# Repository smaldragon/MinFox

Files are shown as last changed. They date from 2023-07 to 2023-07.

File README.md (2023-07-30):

# MinFox

**NOTE: As of now, the board is untested, this README will be updated once proper tests with the physical board have taken place**

This is a minimal 65c02 board for prototyping, it provides ROM, RAM, 6 Chip Select lines (S1-S6), and a large jumper header with all the required signals to connect to daughter boards or to breadboards. The goal is to have a dumb, as simple as possible board for testing peripherals connected to a 65c02 bus.

All components are through hole, as to allow for an easier soldering experience and for the installation of sockets for IC reuse.

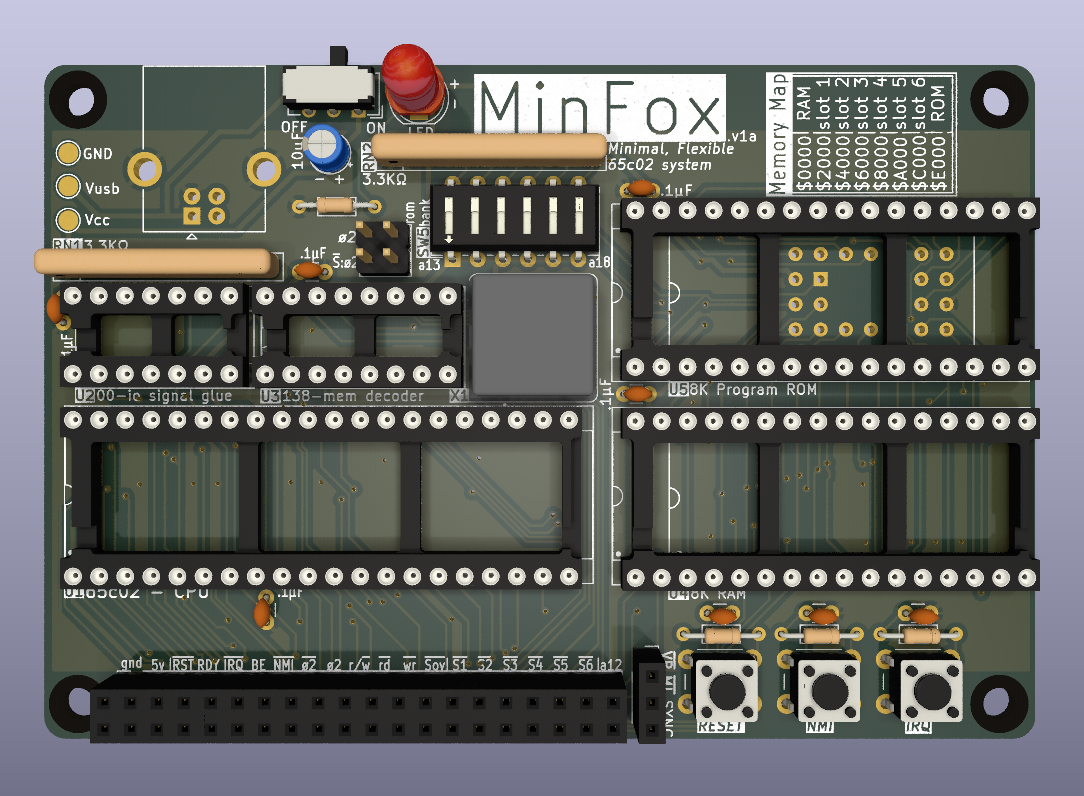
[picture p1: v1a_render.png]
Render of the board (v1a revision)


## Bill of Materials

* wdc65c02 CPU (dip-40)
* 74hc00 Quad Nand Gate (dip-14)
* 74hc138 3-to-8 Decoder (dip-16)
* Standard 62xxx SRAM (dip-28 or dip-32)
* Standard 28cXX EEPROM (dip-28) or 39SF0x0 Flash NOR (dip-32 or PLCC-32)
* Standard 1Mhz Clock Oscillator

* 2x20 Pin Socket (same size as RPi connector)
* 1x3  Pin Socket
* 2x2  Pin Header (+ 2 Jumpers)
* DIP-12 Switch
* Small 6-Pin Power Slide Switch
* USB-B Connector (power)

* 3xPush Buttons
* 1x470Ω
* 3x1KΩ
* 1x10µF Polarized Capacitor
* 8x0.1µF Capacitor
* 2x9pin Resistor Networks

The location and values of all components are also described in the board silk screen.

## Change Log

Board revisions  follow a `v$number$letter` naming scheme, the number symbolizes a board with new features and incompatibilities, while the letter symbolizes fixes and minor tweaks. The current version is **v1a**

### v1a

* Fixed breaking bug with /WR signal
* Added Screw Mounts
* Added Support for DIP-32 RAM and DIP-32/PLCC-32 Flash NOR chips
* Added Jumper for disconnecting clock oscillator
* Added Jumper for gating slot select signals with ø2
* Added dip switch for setting a ROM bank to use
* Added Set Overflow signal to the Connector
* Changed footprint of power slide switch
* Many tweaks to silkscreen

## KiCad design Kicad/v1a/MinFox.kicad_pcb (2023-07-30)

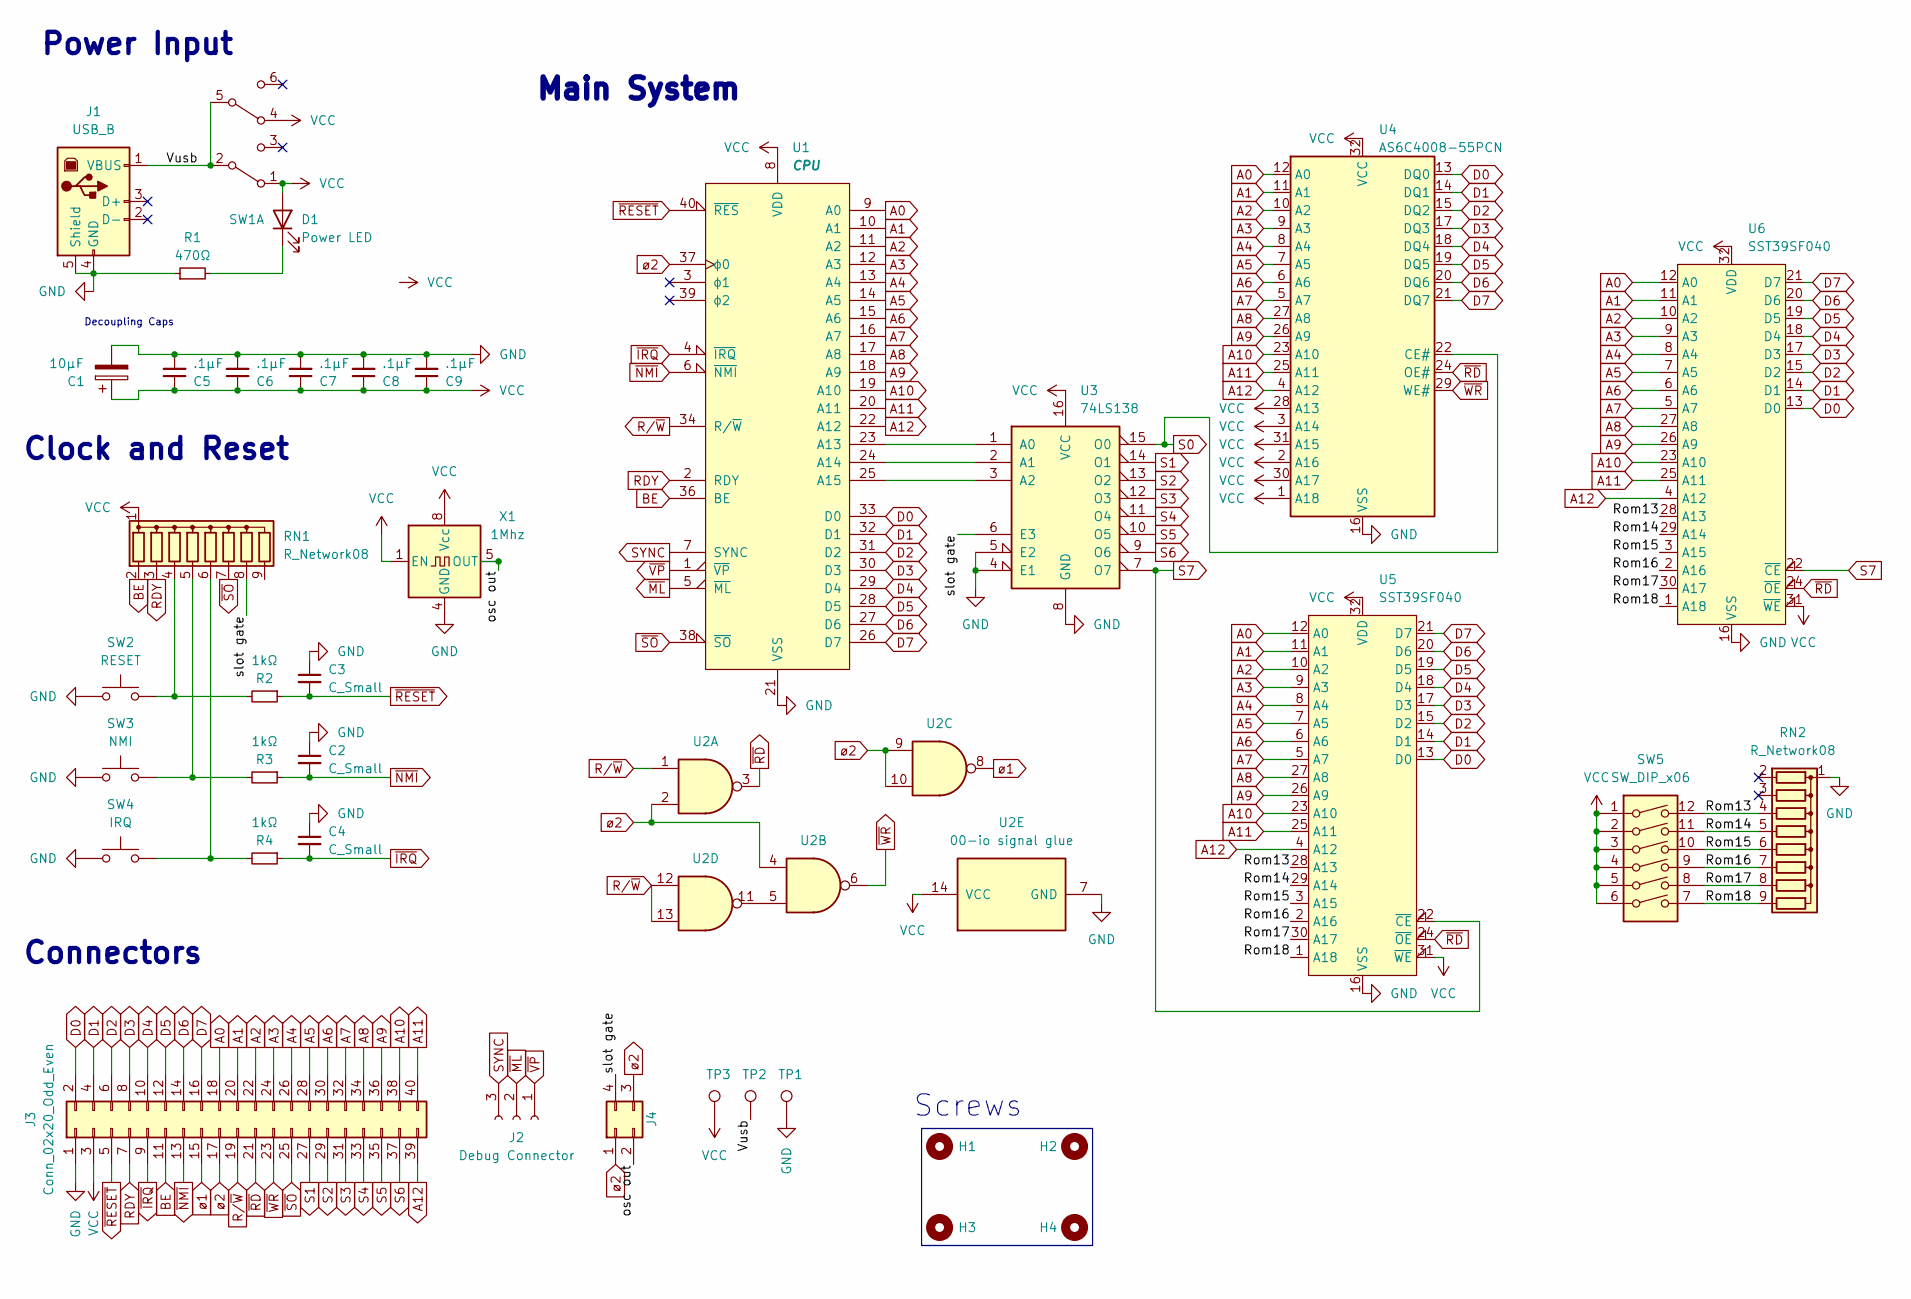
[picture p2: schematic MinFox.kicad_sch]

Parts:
C1: 10µF; CP_Radial_D4.0mm_P1.50mm
C2, C3, C4: C_Small; C_Disc_D3.0mm_W1.6mm_P2.50mm
C5, C6, C7, C8, C9: .1µF; C_Disc_D3.0mm_W1.6mm_P2.50mm
D1: Power LED; LED_D5.0mm
H1, H2, H3, H4: MountingHole; MountingHole_3.2mm_M3
J1: USB_B; USB_B_OST_USB-B1HSxx_Horizontal
J2: Debug Connector; PinSocket_1x03_P2.54mm_Vertical
J3: Conn_02x20_Odd_Even; PinSocket_2x20_P2.54mm_Vertical
J4: Conn_02x02_Counter_Clockwise; PinHeader_2x02_P2.54mm_Vertical
R1: 470Ω; R_Axial_DIN0204_L3.6mm_D1.6mm_P7.62mm_Horizontal
R2, R3, R4: 1kΩ; R_Axial_DIN0204_L3.6mm_D1.6mm_P7.62mm_Horizontal
RN1, RN2: R_Network08; R_Array_SIP9
SW1: SW_DPDT_x2; SW_CuK_JS202011AQN_DPDT_Angled
SW2: RESET; SW_PUSH_6mm
SW3: NMI; SW_PUSH_6mm
SW4: IRQ; SW_PUSH_6mm
SW5: SW_DIP_x06; SW_DIP_SPSTx06_Slide_6.7x16.8mm_W7.62mm_P2.54mm_LowProfile
TP1: GND; TestPoint_Pad_D2.0mm
TP2: Vusb; TestPoint_Pad_D2.0mm
TP3: Vcc; TestPoint_Pad_D2.0mm
U1: CPU; DIP-40_W15.24mm_Socket
U2: 00-io signal glue; DIP-14_W7.62mm_Socket
U3: 74LS138; DIP-16_W7.62mm_Socket
U4: AS6C4008-55PCN; DIP-32_W15.24mm_Socket
U5: SST39SF040; DIP-32_W15.24mm_Socket
U6: SST39SF040; PLCC-32_THT-Socket
X1: 1Mhz; Oscillator_DIP-8

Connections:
/Rom13: RN2.4 (R3), SW5.12, U5.28 (A13), U6.28 (A13)
/Rom14: RN2.5 (R4), SW5.11, U5.29 (A14), U6.29 (A14)
/Rom15: RN2.6 (R5), SW5.10, U5.3 (A15), U6.3 (A15)
/Rom16: RN2.7 (R6), SW5.9, U5.2 (A16), U6.2 (A16)
/Rom17: RN2.8 (R7), SW5.8, U5.30 (A17), U6.30 (A17)
/Rom18: RN2.9 (R8), SW5.7, U5.1 (A18), U6.1 (A18)
/Vusb: J1.1 (VBUS), SW1.2 (B), SW1.5 (B), TP2.1
/osc out: J4.2, X1.5 (OUT)
/slot gate: J4.4, RN1.8 (R7), U3.6 (E3)
A0: J3.18, U1.9 (A0), U4.12 (A0), U5.12 (A0), U6.12 (A0)
A1: J3.20, U1.10 (A1), U4.11 (A1), U5.11 (A1), U6.11 (A1)
A2: J3.22, U1.11 (A2), U4.10 (A2), U5.10 (A2), U6.10 (A2)
A3: J3.24, U1.12 (A3), U4.9 (A3), U5.9 (A3), U6.9 (A3)
A4: J3.26, U1.13 (A4), U4.8 (A4), U5.8 (A4), U6.8 (A4)
A5: J3.28, U1.14 (A5), U4.7 (A5), U5.7 (A5), U6.7 (A5)
A6: J3.30, U1.15 (A6), U4.6 (A6), U5.6 (A6), U6.6 (A6)
A7: J3.32, U1.16 (A7), U4.5 (A7), U5.5 (A7), U6.5 (A7)
A8: J3.34, U1.17 (A8), U4.27 (A8), U5.27 (A8), U6.27 (A8)
A9: J3.36, U1.18 (A9), U4.26 (A9), U5.26 (A9), U6.26 (A9)
A10: J3.38, U1.19 (A10), U4.23 (A10), U5.23 (A10), U6.23 (A10)
A11: J3.40, U1.20 (A11), U4.25 (A11), U5.25 (A11), U6.25 (A11)
A12: J3.39, U1.22 (A12), U4.4 (A12), U5.4 (A12), U6.4 (A12)
BE: J3.11, RN1.2 (R1), U1.36 (BE)
D0: J3.2, U1.33 (D0), U4.13 (DQ0), U5.13 (D0), U6.13 (D0)
D1: J3.4, U1.32 (D1), U4.14 (DQ1), U5.14 (D1), U6.14 (D1)
D2: J3.6, U1.31 (D2), U4.15 (DQ2), U5.15 (D2), U6.15 (D2)
D3: J3.8, U1.30 (D3), U4.17 (DQ3), U5.17 (D3), U6.17 (D3)
D4: J3.10, U1.29 (D4), U4.18 (DQ4), U5.18 (D4), U6.18 (D4)
D5: J3.12, U1.28 (D5), U4.19 (DQ5), U5.19 (D5), U6.19 (D5)
D6: J3.14, U1.27 (D6), U4.20 (DQ6), U5.20 (D6), U6.20 (D6)
D7: J3.16, U1.26 (D7), U4.21 (DQ7), U5.21 (D7), U6.21 (D7)
GND: C1.2, C2.1, C3.1, C4.1, C5.2, C6.2, C7.2, C8.2, C9.2, J1.4 (GND), J1.5 (Shield), J3.1, R1.1, RN2.1 (common), SW2.1, SW3.1, SW4.1, TP1.1, U1.21 (VSS), U2.7 (GND), U3.4 (E1), U3.5 (E2), U3.8 (GND), U4.16 (VSS), U5.16 (VSS), U6.16 (VSS), X1.4 (GND)
unnamed: D1.1 (K), R1.2
unnamed: R2.2, RN1.4 (R3), SW2.2
unnamed: R3.2, RN1.5 (R4), SW3.2
unnamed: R4.2, RN1.6 (R5), SW4.2
unnamed: U1.23 (A13), U3.1 (A0)
unnamed: U1.24 (A14), U3.2 (A1)
unnamed: U1.25 (A15), U3.3 (A2)
unnamed: U2.5, U2.11
RDY: J3.7, RN1.3 (R2), U1.2 (RDY)
R/~W: J3.19, U1.34 (R/~W), U2.1, U2.12, U2.13
S0: U3.15 (O0), U4.22 (CE#)
S1: J3.27, U3.14 (O1)
S2: J3.29, U3.13 (O2)
S3: J3.31, U3.12 (O3)
S4: J3.33, U3.11 (O4)
S5: J3.35, U3.10 (O5)
S6: J3.37, U3.9 (O6)
S7: U3.7 (O7), U5.22 (~CE), U6.22 (~CE)
SYNC: J2.3, U1.7 (SYNC)
VCC: C1.1, C5.1, C6.1, C7.1, C8.1, C9.1, D1.2 (A), J3.3, RN1.1 (common), SW1.1 (A), SW1.4 (A), SW5.1, SW5.2, SW5.3, SW5.4, SW5.5, SW5.6, TP3.1, U1.8 (VDD), U2.14 (VCC), U3.16 (VCC), U4.1 (A18), U4.2 (A16), U4.3 (A14), U4.28 (A13), U4.30 (A17), U4.31 (A15), U4.32 (VCC), U5.31 (~WE), U5.32 (VDD), U6.31 (~WE), U6.32 (VDD), X1.1 (EN), X1.8 (Vcc)
~IRQ: C4.2, J3.9, R4.1, U1.4 (~IRQ)
~ML: J2.2, U1.5 (~ML)
~NMI: C2.2, J3.13, R3.1, U1.6 (~NMI)
~RD: J3.21, U2.3, U4.24 (OE#), U5.24 (~OE), U6.24 (~OE)
~RESET: C3.2, J3.5, R2.1, U1.40 (~RES)
~SO: J3.25, RN1.7 (R6), U1.38 (~SO)
~VP: J2.1, U1.1 (~VP)
~WR: J3.23, U2.6, U4.29 (WE#)
ø1: J3.15, U2.8
ø2: J3.17, J4.1, J4.3, U1.37 (ϕ0), U2.2, U2.4, U2.9, U2.10

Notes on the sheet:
Clock and Reset
Main System
Screws
Decoupling Caps
Power Input
Connectors

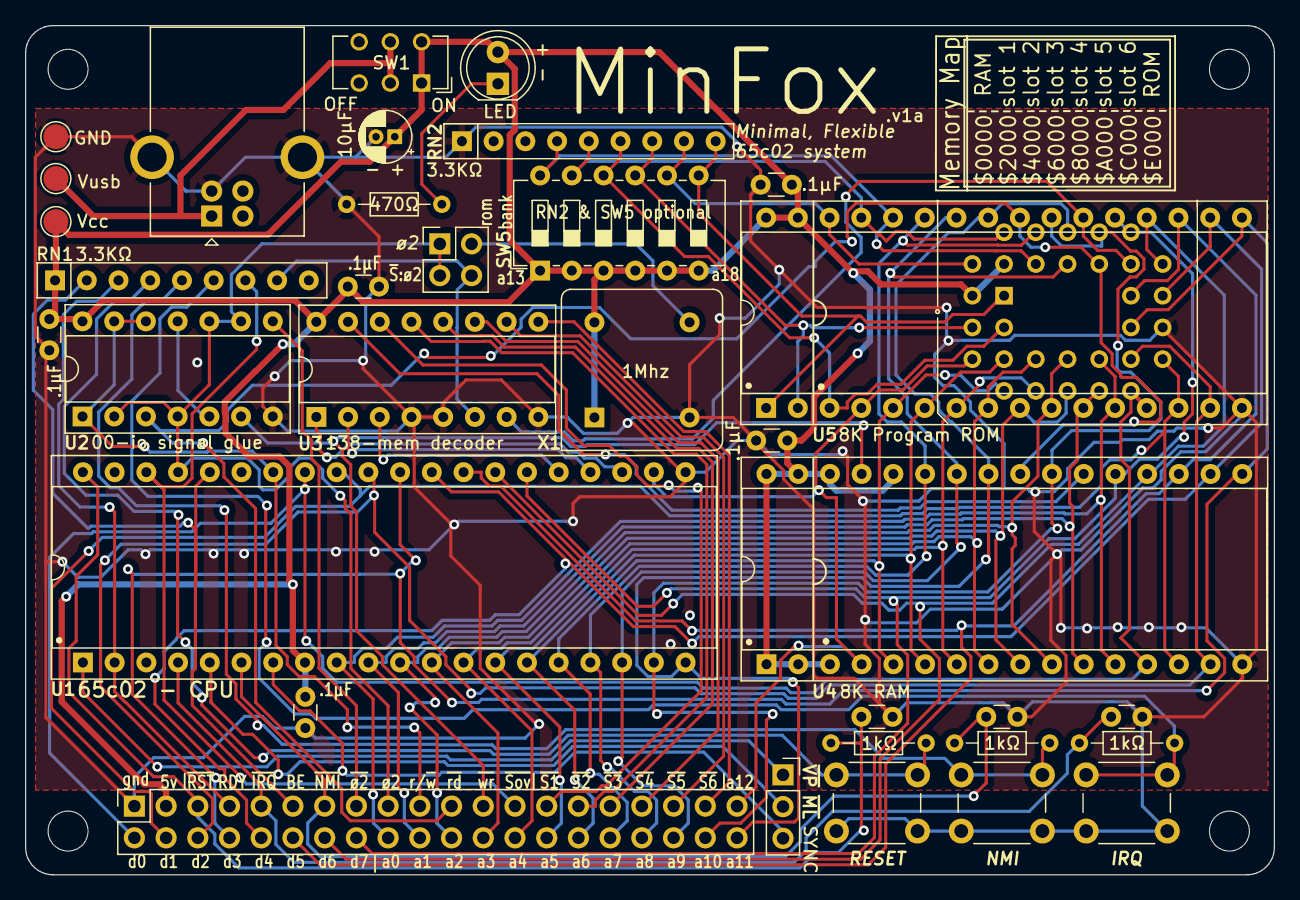
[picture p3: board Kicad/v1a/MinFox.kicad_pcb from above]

Board: 2 copper layers, 100.0 x 68.0 mm, 39 parts (0 on the bottom side), 62 nets.

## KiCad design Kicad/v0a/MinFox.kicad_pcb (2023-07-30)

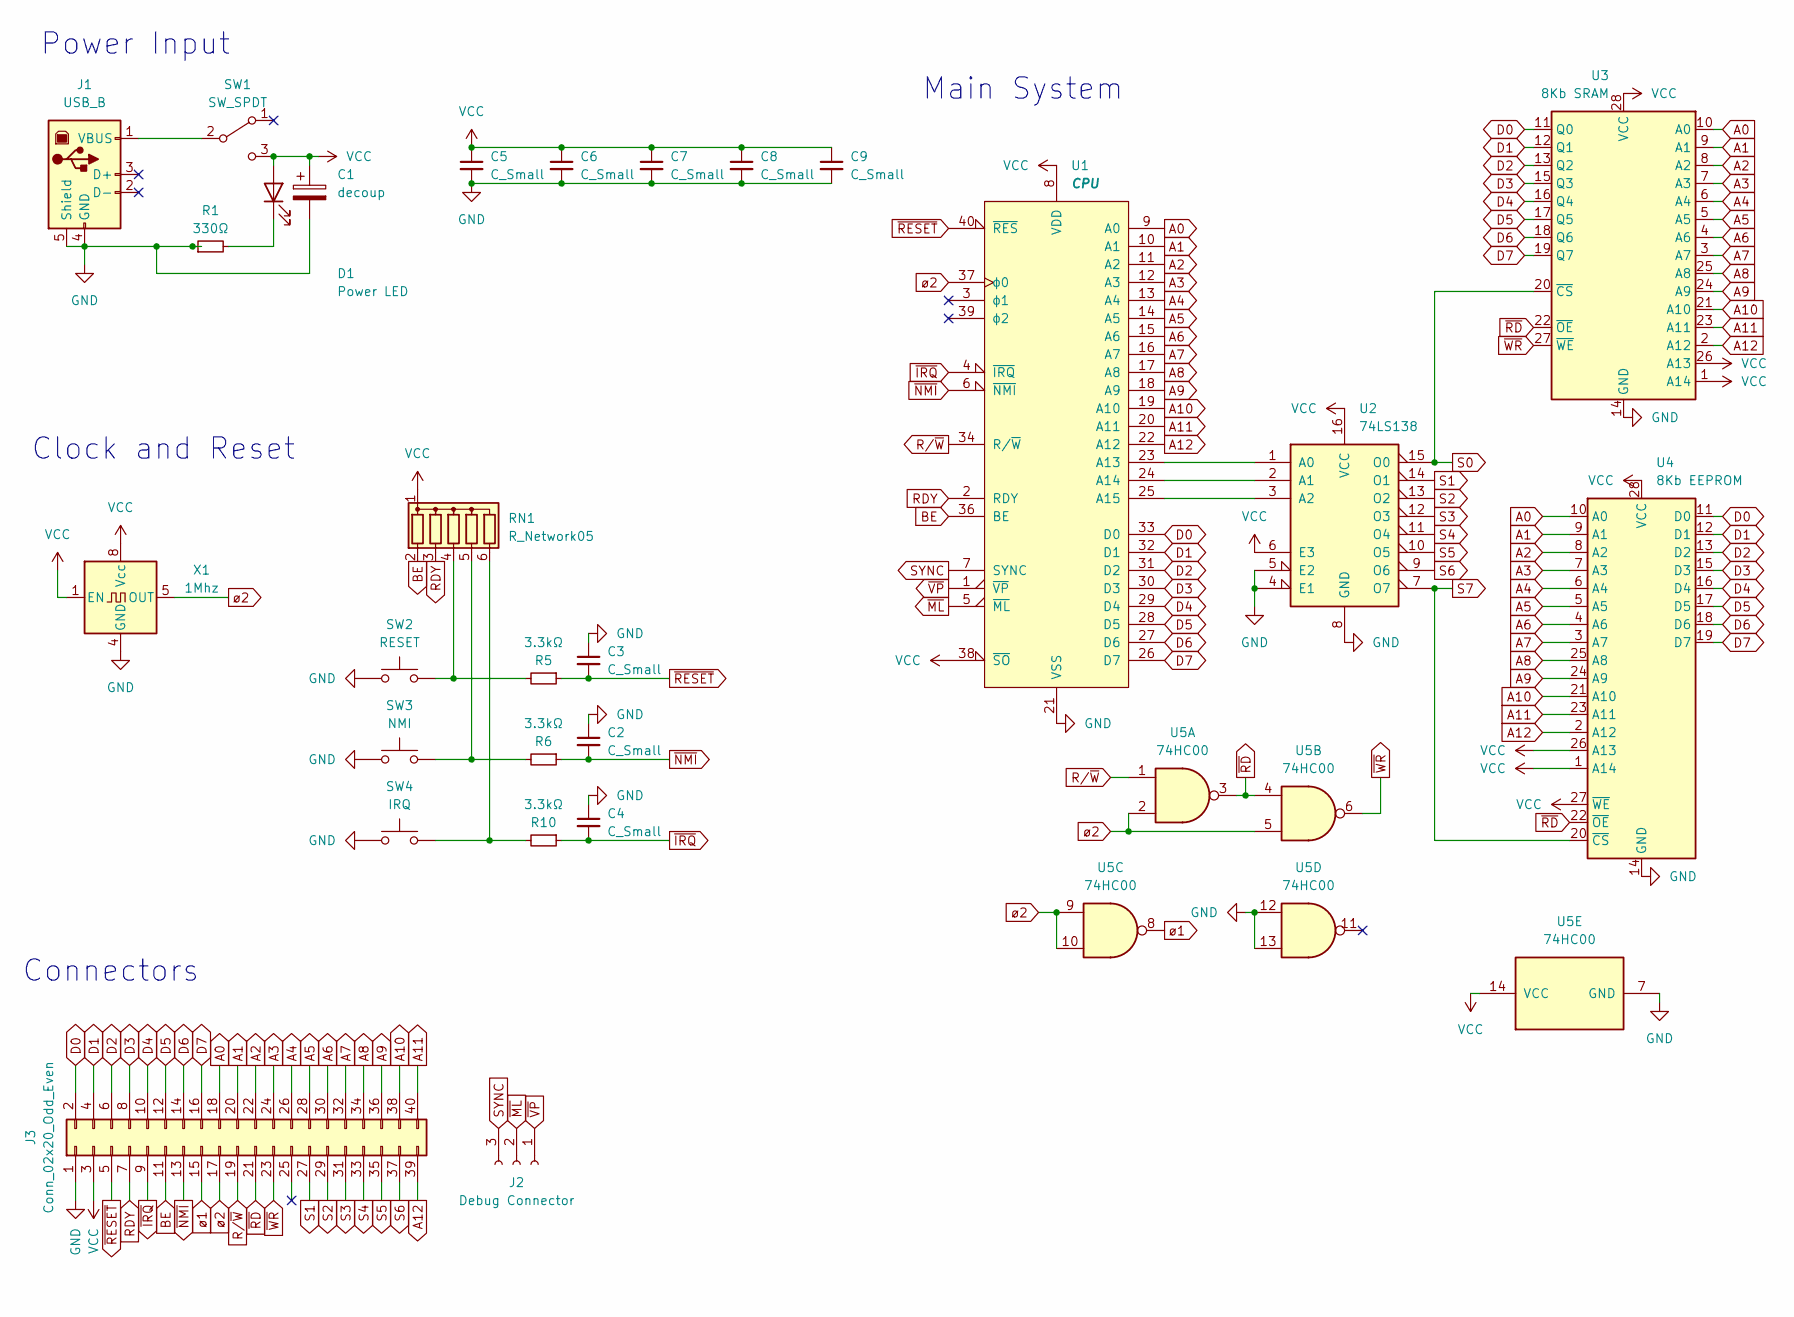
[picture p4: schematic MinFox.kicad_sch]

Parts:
C1: decoup; CP_Radial_D4.0mm_P1.50mm
C2, C3, C4, C5, C6, C7, C8, C9: C_Small; C_Disc_D3.0mm_W1.6mm_P2.50mm
D1: Power LED; LED_D5.0mm
J1: USB_B; USB_B_OST_USB-B1HSxx_Horizontal
J2: Debug Connector; PinSocket_1x03_P2.54mm_Vertical
J3: Conn_02x20_Odd_Even; PinSocket_2x20_P2.54mm_Vertical
R1: 330Ω; R_Axial_DIN0204_L3.6mm_D1.6mm_P5.08mm_Horizontal
R5, R6, R10: 3.3kΩ; R_Axial_DIN0204_L3.6mm_D1.6mm_P5.08mm_Horizontal
RN1: R_Network05; R_Array_SIP6
SW1: SW_SPDT; PinSocket_1x03_P2.54mm_Vertical
SW2: RESET; SW_PUSH_6mm
SW3: NMI; SW_PUSH_6mm
SW4: IRQ; SW_PUSH_6mm
U1: CPU; DIP-40_W15.24mm_Socket
U2: 74LS138; DIP-16_W7.62mm_Socket
U3: 8Kb SRAM; DIP-28_W15.24mm_Socket
U4: 8Kb EEPROM; DIP-28_W15.24mm_Socket
U5: 74HC00; DIP-14_W7.62mm_Socket
X1: 1Mhz; Oscillator_DIP-8

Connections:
A0: J3.18, U1.9 (A0), U3.10 (A0), U4.10 (A0)
A1: J3.20, U1.10 (A1), U3.9 (A1), U4.9 (A1)
A2: J3.22, U1.11 (A2), U3.8 (A2), U4.8 (A2)
A3: J3.24, U1.12 (A3), U3.7 (A3), U4.7 (A3)
A4: J3.26, U1.13 (A4), U3.6 (A4), U4.6 (A4)
A5: J3.28, U1.14 (A5), U3.5 (A5), U4.5 (A5)
A6: J3.30, U1.15 (A6), U3.4 (A6), U4.4 (A6)
A7: J3.32, U1.16 (A7), U3.3 (A7), U4.3 (A7)
A8: J3.34, U1.17 (A8), U3.25 (A8), U4.25 (A8)
A9: J3.36, U1.18 (A9), U3.24 (A9), U4.24 (A9)
A10: J3.38, U1.19 (A10), U3.21 (A10), U4.21 (A10)
A11: J3.40, U1.20 (A11), U3.23 (A11), U4.23 (A11)
A12: J3.39, U1.22 (A12), U3.2 (A12), U4.2 (A12)
BE: J3.11, RN1.2 (R1), U1.36 (BE)
D0: J3.2, U1.33 (D0), U3.11 (Q0), U4.11 (D0)
D1: J3.4, U1.32 (D1), U3.12 (Q1), U4.12 (D1)
D2: J3.6, U1.31 (D2), U3.13 (Q2), U4.13 (D2)
D3: J3.8, U1.30 (D3), U3.15 (Q3), U4.15 (D3)
D4: J3.10, U1.29 (D4), U3.16 (Q4), U4.16 (D4)
D5: J3.12, U1.28 (D5), U3.17 (Q5), U4.17 (D5)
D6: J3.14, U1.27 (D6), U3.18 (Q6), U4.18 (D6)
D7: J3.16, U1.26 (D7), U3.19 (Q7), U4.19 (D7)
GND: C1.2, C2.1, C3.1, C4.1, C5.2, C6.2, C7.2, C8.2, C9.2, J1.4 (GND), J1.5 (Shield), J3.1, R1.1, SW2.1, SW3.1, SW4.1, U1.21 (VSS), U2.4 (E1), U2.5 (E2), U2.8 (GND), U3.14 (GND), U4.14 (GND), U5.7 (GND), U5.12, U5.13, X1.4 (GND)
unnamed: D1.1 (K), R1.2
unnamed: J1.1 (VBUS), SW1.2 (B)
unnamed: R5.2, RN1.4 (R3), SW2.2
unnamed: R6.2, RN1.5 (R4), SW3.2
unnamed: R10.2, RN1.6 (R5), SW4.2
unnamed: U1.23 (A13), U2.1 (A0)
unnamed: U1.24 (A14), U2.2 (A1)
unnamed: U1.25 (A15), U2.3 (A2)
RDY: J3.7, RN1.3 (R2), U1.2 (RDY)
R/~W: J3.19, U1.34 (R/~W), U5.1
S0: U2.15 (O0), U3.20 (~CS)
S1: J3.27, U2.14 (O1)
S2: J3.29, U2.13 (O2)
S3: J3.31, U2.12 (O3)
S4: J3.33, U2.11 (O4)
S5: J3.35, U2.10 (O5)
S6: J3.37, U2.9 (O6)
S7: U2.7 (O7), U4.20 (~CS)
SYNC: J2.3, U1.7 (SYNC)
VCC: C1.1, C5.1, C6.1, C7.1, C8.1, C9.1, D1.2 (A), J3.3, RN1.1 (common), SW1.3 (C), U1.8 (VDD), U1.38 (~SO), U2.6 (E3), U2.16 (VCC), U3.1 (A14), U3.26 (A13), U3.28 (VCC), U4.1 (A14), U4.26 (A13), U4.27 (~WE), U4.28 (VCC), U5.14 (VCC), X1.1 (EN), X1.8 (Vcc)
~IRQ: C4.2, J3.9, R10.1, U1.4 (~IRQ)
~ML: J2.2, U1.5 (~ML)
~NMI: C2.2, J3.13, R6.1, U1.6 (~NMI)
~RD: J3.21, U3.22 (~OE), U4.22 (~OE), U5.3, U5.4
~RESET: C3.2, J3.5, R5.1, U1.40 (~RES)
~VP: J2.1, U1.1 (~VP)
~WR: J3.23, U3.27 (~WE), U5.6
ø1: J3.15, U5.8
ø2: J3.17, U1.37 (ϕ0), U5.2, U5.5, U5.9, U5.10, X1.5 (OUT)

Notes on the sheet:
Clock and Reset
Main System
Power Input
Connectors

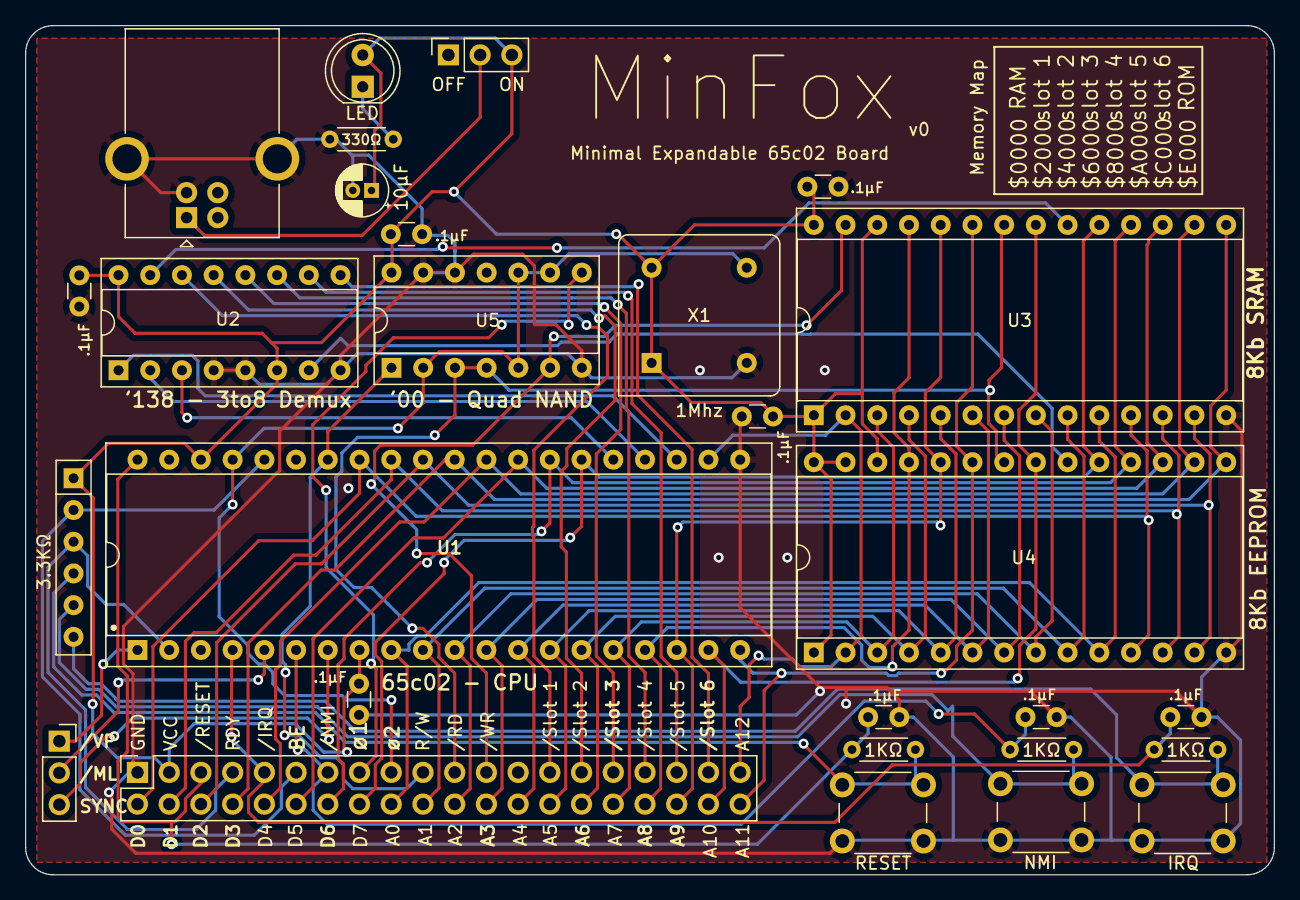
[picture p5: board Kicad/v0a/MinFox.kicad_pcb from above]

Board: 2 copper layers, 100.0 x 68.0 mm, 28 parts (0 on the bottom side), 52 nets.
